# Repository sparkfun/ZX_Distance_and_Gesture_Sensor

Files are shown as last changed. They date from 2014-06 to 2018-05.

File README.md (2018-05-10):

**NOTE:** *This product has been retired from our catalog. If you are looking for more up-to-date info, please check out some of these resources to see how other users are still hacking and improving on this product.*
* *[SparkFun Forum](https://forum.sparkfun.com/)*
* *[Comments Here on GitHub](https://github.com/sparkfun/ZX_Distance_and_Gesture_Sensor/issues)*
* *[IRC Channel](https://www.sparkfun.com/news/263)*

There is another version available with the surface mount ICs [ ZX Distance and Gesture Sensor SMD - [SEN-13162](https://www.sparkfun.com/products/13162) ] so the associated Arduino Library will be kept open => [SparkFun_ZX_distance_and_Gesture_Sensor_Arduino_Library](https://github.com/sparkfun/SparkFun_ZX_Distance_and_Gesture_Sensor_Arduino_Library). 

SparkFun ZX Distance and Gesture Sensor
========================================

SparkFun ZX Distance and Gesture Sensor

[*SparkFun ZX Distance and Gesture Sensor (SEN-12780)*](https://www.sparkfun.com/products/12780)

Infrared sensor capable of determining an object's distance from the sensor and its relative position between the IR LEDs. The sensor is capable of determining a 2-dimensional location of an object as well as determining several basic gestures.

Repository Contents
-------------------

* **/Hardware** - Eagle design files (.brd, .sch)
* **/Libraries** - Libraries for use with the ZX Distance and Gesture Sensor
* **/Production** - Production panel files (.brd)

Documentation
--------------

* **[Library](https://github.com/sparkfun/SparkFun_ZX_Distance_and_Gesture_Sensor_Arduino_Library)** - Arduino library for the ZX Distance and Gesture Sensor.
* **[Hookup Guide](https://learn.sparkfun.com/tutorials/zx-distance-and-gesture-sensor-hookup-guide)** - Basic hookup guide for the ZX Distance and Gesture Sensor.
* **[SparkFun Fritzing repo](https://github.com/sparkfun/Fritzing_Parts)** - Fritzing diagrams for SparkFun products.

Product Versions
----------------

* [SEN-12780](https://www.sparkfun.com/products/12780)- ZX Distance and Gesture Sensor

Version History
---------------

* [H_1.0_L_1.0.2](https://github.com/sparkfun/ZX_Distance_and_Gesture_Sensor/tree/H_1.0_L_1.0.2) - Fixed Arduino library name
* [H_1.0_L_1.0.1](https://github.com/sparkfun/ZX_Distance_and_Gesture_Sensor/tree/H_1.0_L_1.0.1) - Fixed typo in Arduino library properties file
* [H_1.0_L_1.0.0](https://github.com/sparkfun/ZX_Distance_and_Gesture_Sensor/tree/H_1.0_L_1.0.0) - Initial release

License Information
-------------------

This product is _**open source**_! 

Please review the LICENSE.md file for license information. 

If you have any questions or concerns on licensing, please contact techsupport@sparkfun.com.

Distributed as-is; no warranty is given.

- Your friends at SparkFun.

_This is a collaboration with [XYZ Interactive](http://www.gesturesense.com/xyz)_

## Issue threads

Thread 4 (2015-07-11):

ZX_RRNG address correct?

akohlsmith, 2015-07-11:
I'm the author of the ZX software (the software in the sensor itself). Are you sure that you have the ZX_RRNG address correct? REGVER 0x01 MODEL 0x01 should not report anything at register 0x0e (i.e. reading register 0x0e will always return zero).

If you could verify this behaviour this on your production sensors I'll fork the code and send a pull request.

ShawnHymel, 2015-08-13:
Hi Andrew, sorry it's taken me so long to get to this bug. I spit out the contents of LRNG and RRNG from our production ZX Sensor, and they both read "0." According to the [I2C Register Map](https://cdn.sparkfun.com/datasheets/Sensors/Proximity/XYZ%20I2C%20Registers%20v1.zip) that XYZ sent me, LRNG and RRNG are implemented. I just don't see them doing any thing right now. I don't mind leaving the definitions in, because they aren't used in the code.

bboyho, 2018-05-10:
Unfortunately, the ZX distance and gesture sensor [SKU-12780](https://www.sparkfun.com/products/retired/12780) has been retired. This looks like the issue has been addressed and will be left as is.  I will be closing this issue and archiving the GitHub repository.

There is another version available with the surface mount ICs [ ZX Distance and Gesture Sensor SMD [SEN-13162](https://www.sparkfun.com/products/13162) ] so the associated Arduino Library will be kept open [SparkFun_ZX_distance_and_Gesture_Sensor_Arduino_Library](https://github.com/sparkfun/SparkFun_ZX_Distance_and_Gesture_Sensor_Arduino_Library).

Closed 2018-05-10.

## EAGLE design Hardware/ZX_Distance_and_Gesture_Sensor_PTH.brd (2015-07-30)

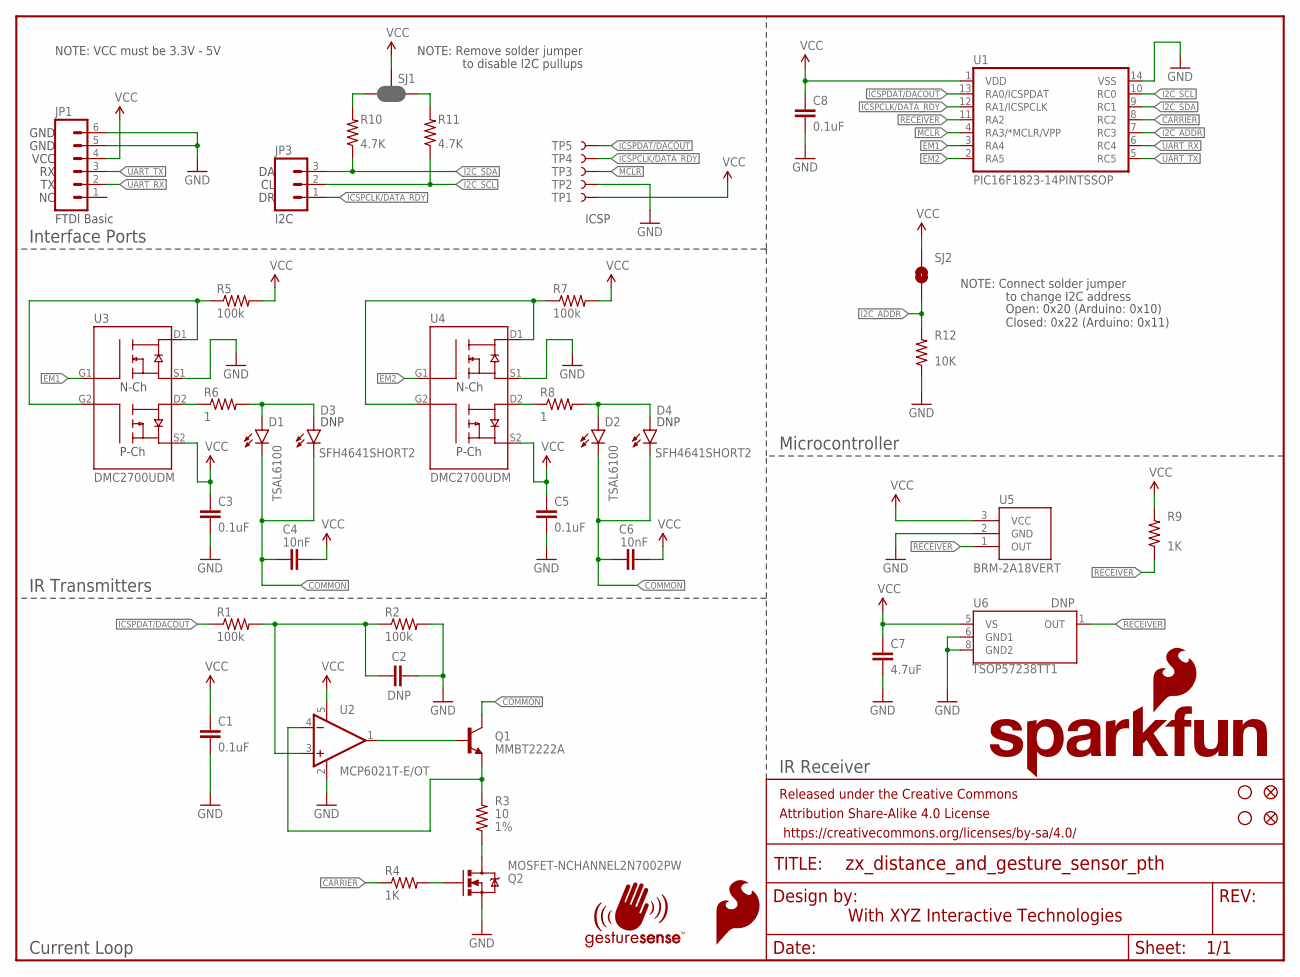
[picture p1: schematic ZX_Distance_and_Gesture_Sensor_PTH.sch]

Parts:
C1, C3, C5, C8: 0.1uF; 0603-CAP
C2: DNP; 0603-CAP
C4, C6: 10nF; 0603-CAP
C7: 4.7uF; 0603-CAP
D1, D2: LED-IR-THRUTSAL6100; LED5MM
D3, D4: SFH4641SHORT2; SFH4641-SHORT2
FID1, FID2: FIDUCIAL1X2; FIDUCIAL-1X2
FRAME1: FRAME-LETTER; CREATIVE_COMMONS
JP1: M06NO_SILK_FEMALE_PTH; 1X06_NO_SILK
JP3: M031X03_NO_SILK; 1X03_NO_SILK
LOGO1: SFE_LOGO_FLAME.1_INCH; SFE_LOGO_FLAME_.1
Q1: MMBT2222A; SOT23-3
Q2: MOSFET-NCHANNEL2N7002PW; SOT323
R1, R2, R5, R7: 100k; 0603-RES
R3: 10; 0603-RES
R4, R9: 1K; 0603-RES
R6, R8: 1; 0603-RES
R10, R11: 4.7K; 0603-RES
R12: 10K; 0603-RES
SJ1: JUMPER-PAD-3-NC_BY_PASTE; PAD-JUMPER-3-NC_BY_PASTE_YES_SILK_FULL_BOX
SJ2: JUMPER-PAD-2-NOYES_SILK; PAD-JUMPER-2-NO_YES_SILK
STANDOFF1, STANDOFF2: STAND-OFF
TP1, TP2, TP3, TP4, TP5: TEST-POINT3X4; PAD.03X.04
U1: PIC16F1823-14PINTSSOP; TSSOP14
U2: MCP6021T-E/OT; SOT23-5
U3, U4: DMC2700UDM; SOT26
U5: BRM-2A18VERT; BRM-2508_VERT
U6: TSOP57238TT1; TSOP572
U$5: SFE_LOGO_NAME_FLAME.1_INCH; SFE_LOGO_NAME_FLAME_.1
U$6: GESTURESENSE_LOGOSTEXT; GESTURESENSE_TEXT

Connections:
CARRIER: R4.1, U1.8 (RC2)
COMMON: C4.1, C6.1, D1.K (C), D2.K (C), D3.C, D4.C, Q1.3 (C)
EM1: U1.3 (RA4), U3.G1
EM2: U1.2 (RA5), U4.G1
GND: C1.2, C2.2, C3.2, C5.2, C7.2, C8.2, JP1.5, JP1.6, Q2.2 (S), R2.2, R12.1, TP2.P$1, U1.14 (VSS), U2.2 (V-), U3.S1, U4.S1, U5.2 (GND), U6.6 (GND1), U6.8 (GND2)
I2C_ADDR: R12.2, SJ2.1, U1.7 (RC3)
I2C_SCL: JP3.2, R11.1, U1.10 (RC0)
I2C_SDA: JP3.3, R10.1, U1.9 (RC1)
ICSPCLK/DATA_RDY: JP3.1, TP4.P$1, U1.12 (RA1/ICSPCLK)
ICSPDAT/DACOUT: R1.1, TP5.P$1, U1.13 (RA0/ICSPDAT)
MCLR: TP3.P$1, U1.4 (RA3/*MCLR/VPP)
unnamed: C2.1, R1.2, R2.1, U2.3 (+IN)
unnamed: Q1.2 (E), R3.2, U2.4 (-IN)
unnamed: Q1.1 (B), U2.1 (OUT)
unnamed: Q2.3 (D), R3.1
unnamed: Q2.1 (G), R4.2
unnamed: R6.1, U3.D2
unnamed: D1.A, D3.A, R6.2
unnamed: R5.1, U3.D1, U3.G2
unnamed: R7.1, U4.D1, U4.G2
unnamed: R10.2, SJ1.3
unnamed: R8.1, U4.D2
unnamed: D2.A, D4.A, R8.2
unnamed: R11.2, SJ1.1
RECEIVER: R9.1, U1.11 (RA2), U5.1 (OUT), U6.1 (OUT)
UART_RX: JP1.2, U1.6 (RC4)
UART_TX: JP1.3, U1.5 (RC5)
VCC: C1.1, C3.1, C4.2, C5.1, C6.2, C7.1, C8.1, JP1.4, R5.2, R7.2, R9.2, SJ1.2, SJ2.2, TP1.P$1, U1.1 (VDD), U2.5 (V+), U3.S2, U4.S2, U5.3 (VCC), U6.5 (VS)

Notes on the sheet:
With XYZ Interactive Technologies
FTDI Basic
I2C
ICSP
NOTE: Remove solder jumper
to disable I2C pullups
NOTE: Connect solder jumper
to change I2C address
Open: 0x20 (Arduino: 0x10) Closed: 0x22 (Arduino: 0x11)
Interface Ports
IR Transmitters
Current Loop
Microcontroller
IR Receiver
VCC
GND
DNP
NOTE: VCC must be 3.3V - 5V

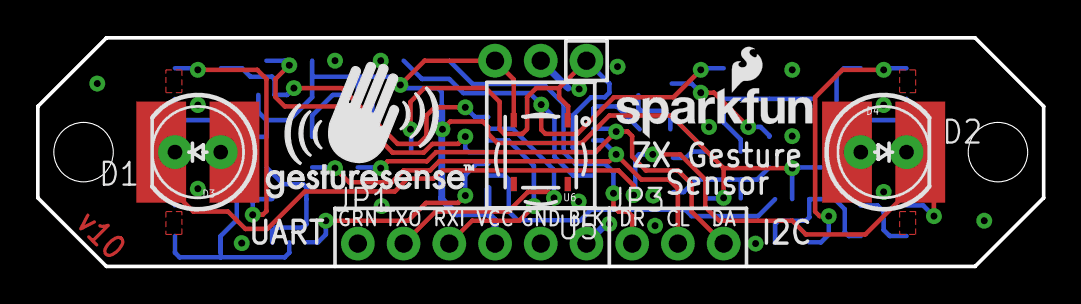
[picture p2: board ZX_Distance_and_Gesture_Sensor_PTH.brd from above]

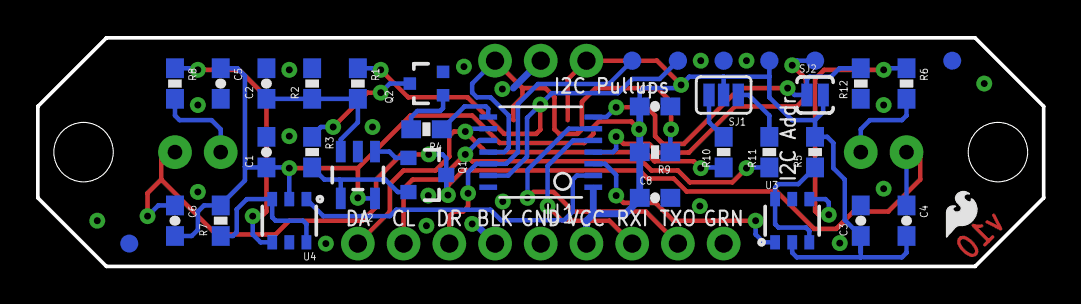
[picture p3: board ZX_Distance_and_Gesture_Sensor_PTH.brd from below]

Board: 2 copper layers, 55.9 x 12.7 mm, 49 parts (36 on the bottom side), 28 nets.

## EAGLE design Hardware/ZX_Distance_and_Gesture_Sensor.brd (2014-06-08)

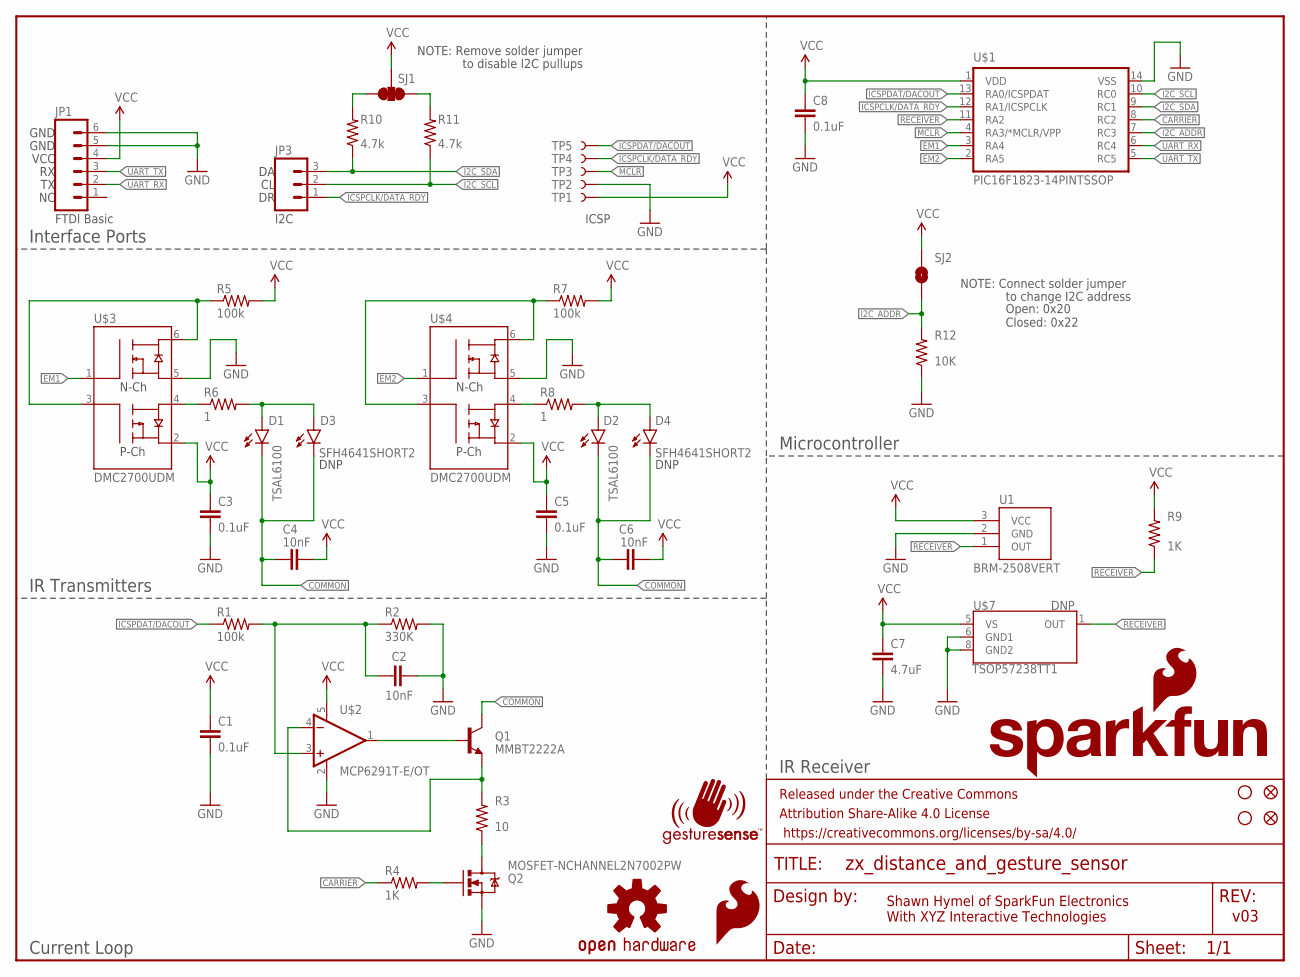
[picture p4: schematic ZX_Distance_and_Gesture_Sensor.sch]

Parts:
C1, C3, C5, C8: 0.1uF; 0603-CAP
C2, C4, C6: 10nF; 0603-CAP
C7: 4.7uF; 0603-CAP
D1, D2: LED-IR-THRUTSAL6100; LED5MM
D3, D4: SFH4641SHORT2; SFH4641-SHORT2
FID1, FID2: FIDUCIAL1X2; FIDUCIAL-1X2
FRAME1: FRAME-LETTER; CREATIVE_COMMONS
JP1: M06NO_SILK; 1X06_NO_SILK
JP3: M031X03_NO_SILK; 1X03_NO_SILK
LOGO1: SFE_LOGO_FLAME.1_INCH; SFE_LOGO_FLAME_.1
LOGO2: OSHW-LOGOS; OSHW-LOGO-S
Q1: MMBT2222A; SOT23-3
Q2: MOSFET-NCHANNEL2N7002PW; SOT323
R1, R5, R7: 100k; 0603-RES
R2: 330K; 0603-RES
R3: 10; 0603-RES
R4, R9: 1K; 0603-RES
R6, R8: 1; 0603-RES
R10, R11: 4.7k; 0603
R12: 10K; 0603-RES
SJ1: SOLDERJUMPER_2WAYPASTE1&2&3; SJ_3_PASTE1&2&3
SJ2: SOLDERJUMPERNO; SJ_2S-NO
STANDOFF1, STANDOFF2: STAND-OFF
TP1, TP2, TP3, TP4, TP5: TEST-POINT3X4; PAD.03X.04
U1: BRM-2508VERT; BRM-2508_VERT
U$1: PIC16F1823-14PINTSSOP; TSSOP14
U$2: MCP6291T-E/OT; SOT23-5
U$3, U$4: DMC2700UDM; SOT26
U$5: SFE_LOGO_NAME_FLAME.1_INCH; SFE_LOGO_NAME_FLAME_.1
U$6: GESTURESENSE_LOGOSTEXT; GESTURESENSE_TEXT
U$7: TSOP57238TT1; TSOP572

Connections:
CARRIER: R4.1, U$1.8 (RC2)
COMMON: C4.1, C6.1, D1.K (C), D2.K (C), D3.C, D4.C, Q1.3 (C)
EM1: U$1.3 (RA4), U$3.1 (G1)
EM2: U$1.2 (RA5), U$4.1 (G1)
GND: C1.2, C2.2, C3.2, C5.2, C7.2, C8.2, JP1.5, JP1.6, Q2.2 (S), R2.2, R12.1, TP2.P$1, U1.2 (GND), U$1.14 (VSS), U$2.2 (V-), U$3.5 (S1), U$4.5 (S1), U$7.6 (GND1), U$7.8 (GND2)
I2C_ADDR: R12.2, SJ2.1, U$1.7 (RC3)
I2C_SCL: JP3.2, R11.1, U$1.10 (RC0)
I2C_SDA: JP3.3, R10.1, U$1.9 (RC1)
ICSPCLK/DATA_RDY: JP3.1, TP4.P$1, U$1.12 (RA1/ICSPCLK)
ICSPDAT/DACOUT: R1.1, TP5.P$1, U$1.13 (RA0/ICSPDAT)
MCLR: TP3.P$1, U$1.4 (RA3/*MCLR/VPP)
unnamed: C2.1, R1.2, R2.1, U$2.3 (+IN)
unnamed: Q1.2 (E), R3.2, U$2.4 (-IN)
unnamed: Q1.1 (B), U$2.1 (OUT)
unnamed: Q2.3 (D), R3.1
unnamed: Q2.1 (G), R4.2
unnamed: R6.1, U$3.4 (D2)
unnamed: D1.A, D3.A, R6.2
unnamed: R5.1, U$3.3 (G2), U$3.6 (D1)
unnamed: R7.1, U$4.3 (G2), U$4.6 (D1)
unnamed: R10.2, SJ1.3
unnamed: R8.1, U$4.4 (D2)
unnamed: D2.A, D4.A, R8.2
unnamed: R11.2, SJ1.1
RECEIVER: R9.1, U1.1 (OUT), U$1.11 (RA2), U$7.1 (OUT)
UART_RX: JP1.2, U$1.6 (RC4)
UART_TX: JP1.3, U$1.5 (RC5)
VCC: C1.1, C3.1, C4.2, C5.1, C6.2, C7.1, C8.1, JP1.4, R5.2, R7.2, R9.2, SJ1.2, SJ2.2, TP1.P$1, U1.3 (VCC), U$1.1 (VDD), U$2.5 (V+), U$3.2 (S2), U$4.2 (S2), U$7.5 (VS)

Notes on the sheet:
v03
Shawn Hymel of SparkFun Electronics With XYZ Interactive Technologies
FTDI Basic
I2C
ICSP
NOTE: Remove solder jumper
to disable I2C pullups
NOTE: Connect solder jumper
to change I2C address
Open: 0x20 Closed: 0x22
Interface Ports
IR Transmitters
Current Loop
Microcontroller
IR Receiver
VCC
GND
DNP

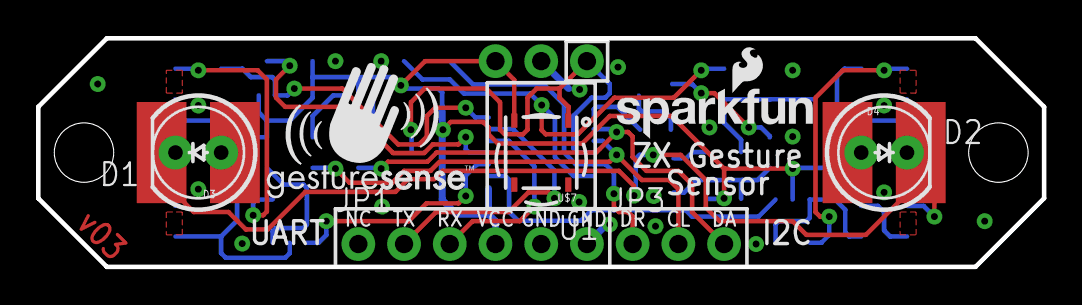
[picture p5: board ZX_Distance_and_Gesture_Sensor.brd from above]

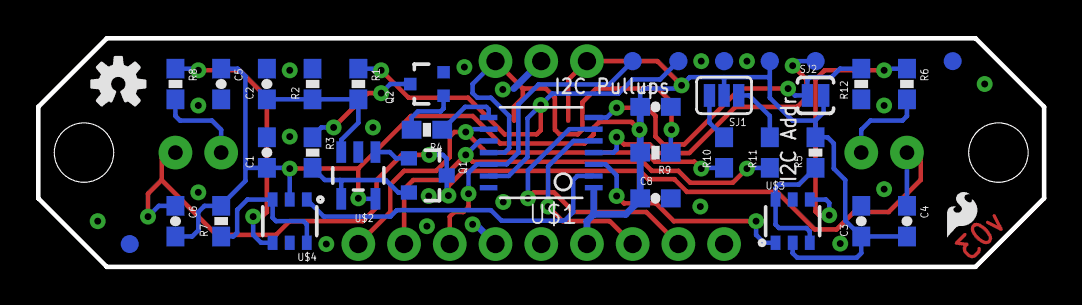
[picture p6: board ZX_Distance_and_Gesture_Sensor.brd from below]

Board: 2 copper layers, 55.9 x 12.7 mm, 50 parts (37 on the bottom side), 28 nets.

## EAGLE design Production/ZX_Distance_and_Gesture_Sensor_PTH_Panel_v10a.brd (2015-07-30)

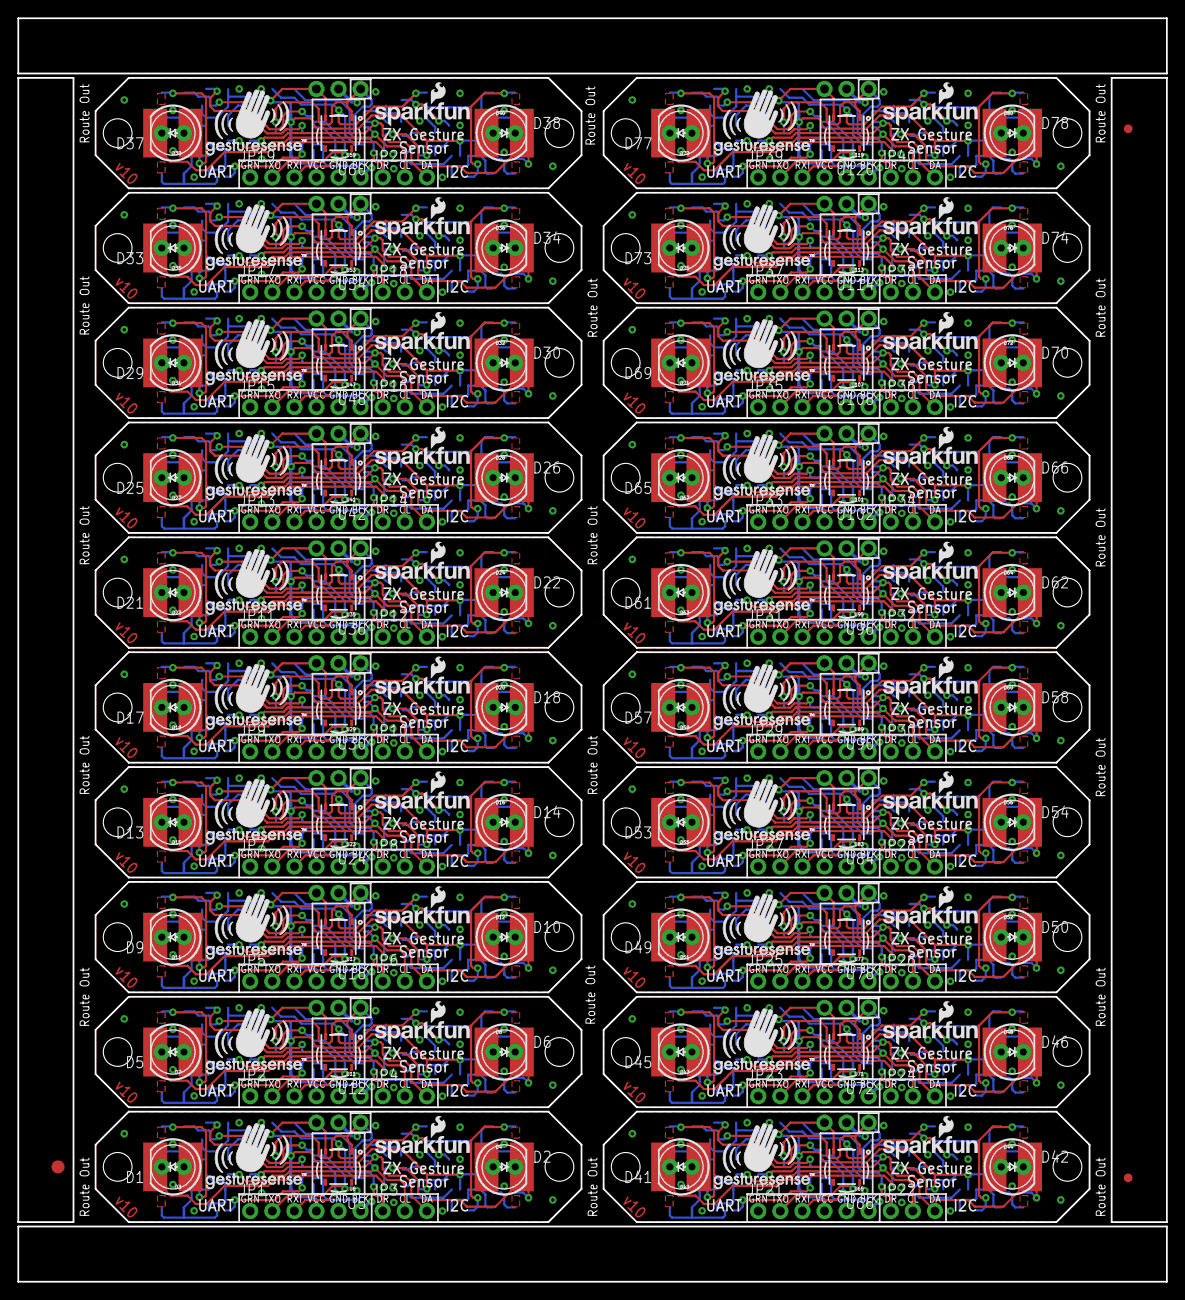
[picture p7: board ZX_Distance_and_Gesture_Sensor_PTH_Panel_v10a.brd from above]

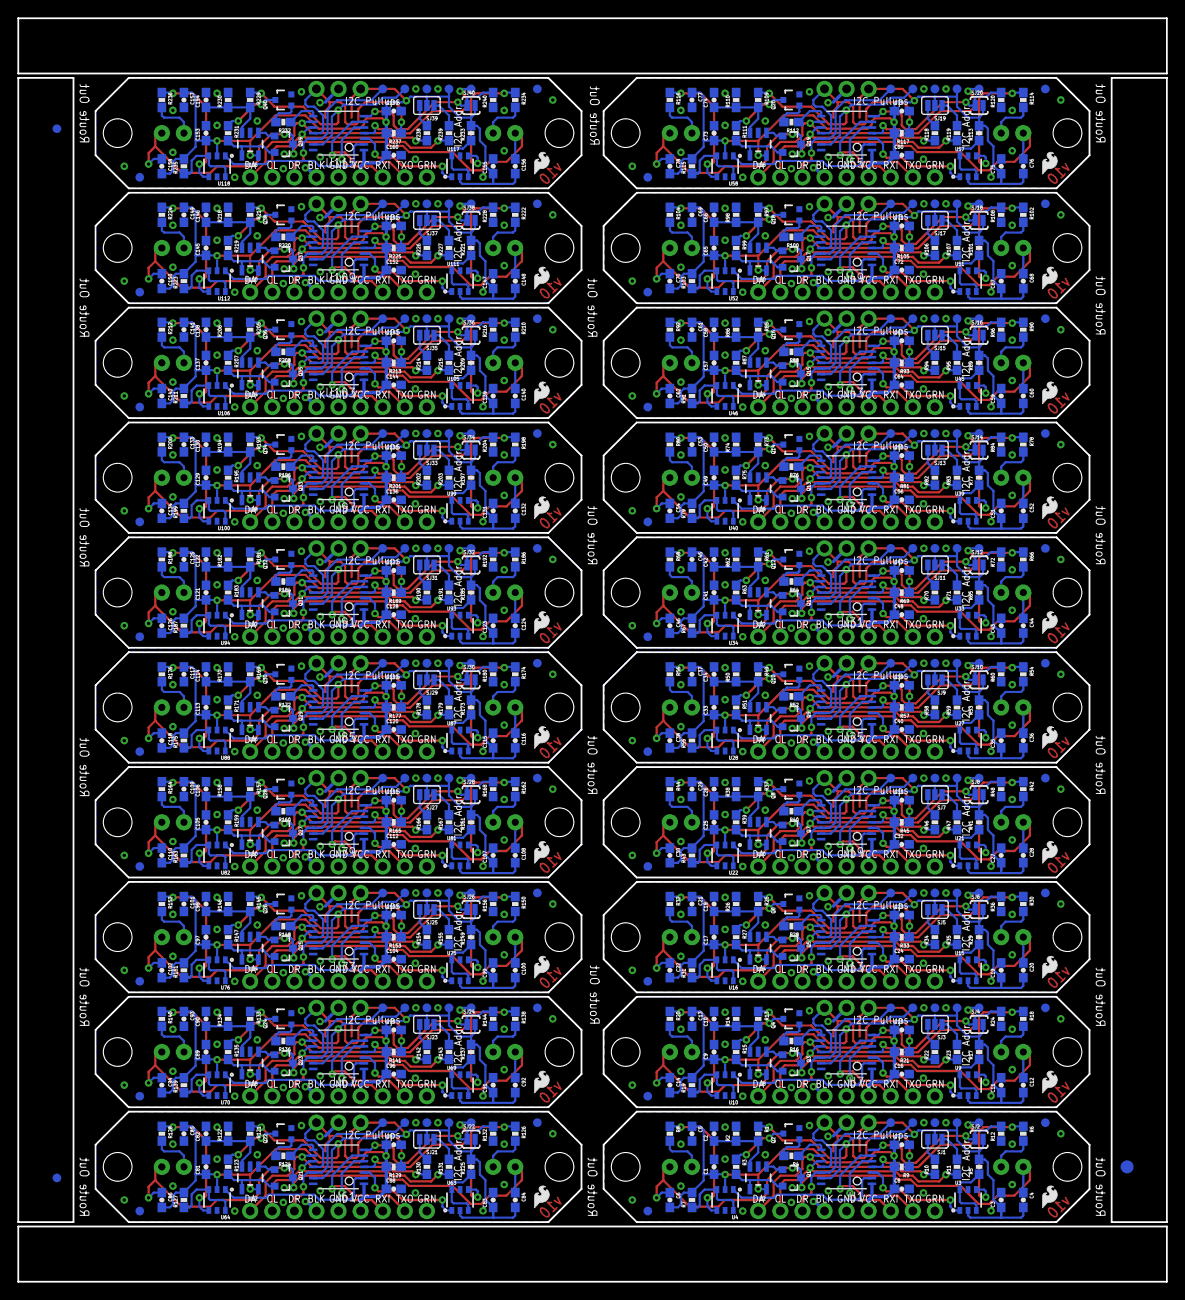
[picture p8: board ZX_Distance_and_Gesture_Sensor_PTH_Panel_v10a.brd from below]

Board: 2 copper layers, 132.1 x 145.3 mm, 966 parts (723 on the bottom side), 560 nets.

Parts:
C1, C3, C5, C8, C9, C11, C13, C16, C17, C19, C21, C24, C25, C27, C29, C32, C33, C35, C37, C40, C41, C43, C45, C48, C49, C51, C53, C56, C57, C59, C61, C64, C65, C67, C69, C72, C73, C75, C77, C80, C81, C83, C85, C88, C89, C91, C93, C96, C97, C99, C101, C104, C105, C107, C109, C112, C113, C115, C117, C120, C121, C123, C125, C128, C129, C131, C133, C136, C137, C139, C141, C144, C145, C147, C149, C152, C153, C155, C157, C160: 0.1uF; 0603-CAP
C2, C10, C18, C26, C34, C42, C50, C58, C66, C74, C82, C90, C98, C106, C114, C122, C130, C138, C146, C154: DNP; 0603-CAP
C4, C6, C12, C14, C20, C22, C28, C30, C36, C38, C44, C46, C52, C54, C60, C62, C68, C70, C76, C78, C84, C86, C92, C94, C100, C102, C108, C110, C116, C118, C124, C126, C132, C134, C140, C142, C148, C150, C156, C158: 10nF; 0603-CAP
C7, C15, C23, C31, C39, C47, C55, C63, C71, C79, C87, C95, C103, C111, C119, C127, C135, C143, C151, C159: 4.7uF; 0603-CAP
D1, D2, D5, D6, D9, D10, D13, D14, D17, D18, D21, D22, D25, D26, D29, D30, D33, D34, D37, D38, D41, D42, D45, D46, D49, D50, D53, D54, D57, D58, D61, D62, D65, D66, D69, D70, D73, D74, D77, D78: LED-IR-THRUTSAL6100; LED5MM
D3, D4, D7, D8, D11, D12, D15, D16, D19, D20, D23, D24, D27, D28, D31, D32, D35, D36, D39, D40, D43, D44, D47, D48, D51, D52, D55, D56, D59, D60, D63, D64, D67, D68, D71, D72, D75, D76, D79, D80: SFH4641SHORT2; SFH4641-SHORT2
E$1, E$3: FIDUCIAL-1.5X3
E$2, E$4, E$5, E$6: FIDUCIAL-1X2
FID1, FID2, FID3, FID4, FID5, FID6, FID7, FID8, FID9, FID10, FID11, FID12, FID13, FID14, FID15, FID16, FID17, FID18, FID19, FID20, FID21, FID22, FID23, FID24, FID25, FID26, FID27, FID28, FID29, FID30, FID31, FID32, FID33, FID34, FID35, FID36, FID37, FID38, FID39, FID40: FIDUCIAL1X2; FIDUCIAL-1X2
JP1, JP2, JP5, JP7, JP9, JP11, JP13, JP15, JP17, JP19, JP21, JP23, JP25, JP27, JP29, JP31, JP33, JP35, JP37, JP39: 1X06_NO_SILK
JP3, JP4, JP6, JP8, JP10, JP12, JP14, JP16, JP18, JP20, JP22, JP24, JP26, JP28, JP30, JP32, JP34, JP36, JP38, JP40: 1X03_NO_SILK
LOGO1, LOGO2, LOGO3, LOGO4, LOGO5, LOGO6, LOGO7, LOGO8, LOGO9, LOGO10, LOGO11, LOGO12, LOGO13, LOGO14, LOGO15, LOGO16, LOGO17, LOGO18, LOGO19, LOGO20: SFE_LOGO_FLAME.1_INCH; SFE_LOGO_FLAME_.1
Q1, Q3, Q5, Q7, Q9, Q11, Q13, Q15, Q17, Q19, Q21, Q23, Q25, Q27, Q29, Q31, Q33, Q35, Q37, Q39: MMBT2222A; SOT23-3
Q2, Q4, Q6, Q8, Q10, Q12, Q14, Q16, Q18, Q20, Q22, Q24, Q26, Q28, Q30, Q32, Q34, Q36, Q38, Q40: MOSFET-NCHANNEL2N7002PW; SOT323
R1, R2, R5, R7, R13, R14, R17, R19, R25, R26, R29, R31, R37, R38, R41, R43, R49, R50, R53, R55, R61, R62, R65, R67, R73, R74, R77, R79, R85, R86, R89, R91, R97, R98, R101, R103, R109, R110, R113, R115, R121, R122, R125, R127, R133, R134, R137, R139, R145, R146, R149, R151, R157, R158, R161, R163, R169, R170, R173, R175, R181, R182, R185, R187, R193, R194, R197, R199, R205, R206, R209, R211, R217, R218, R221, R223, R229, R230, R233, R235: 100k; 0603-RES
R3, R15, R27, R39, R51, R63, R75, R87, R99, R111, R123, R135, R147, R159, R171, R183, R195, R207, R219, R231: 10; 0603-RES
R4, R9, R16, R21, R28, R33, R40, R45, R52, R57, R64, R69, R76, R81, R88, R93, R100, R105, R112, R117, R124, R129, R136, R141, R148, R153, R160, R165, R172, R177, R184, R189, R196, R201, R208, R213, R220, R225, R232, R237: 1K; 0603-RES
R6, R8, R18, R20, R30, R32, R42, R44, R54, R56, R66, R68, R78, R80, R90, R92, R102, R104, R114, R116, R126, R128, R138, R140, R150, R152, R162, R164, R174, R176, R186, R188, R198, R200, R210, R212, R222, R224, R234, R236: 1; 0603-RES
R10, R11, R22, R23, R34, R35, R46, R47, R58, R59, R70, R71, R82, R83, R94, R95, R106, R107, R118, R119, R130, R131, R142, R143, R154, R155, R166, R167, R178, R179, R190, R191, R202, R203, R214, R215, R226, R227, R238, R239: 4.7K; 0603-RES
R12, R24, R36, R48, R60, R72, R84, R96, R108, R120, R132, R144, R156, R168, R180, R192, R204, R216, R228, R240: 10K; 0603-RES
SJ1, SJ3, SJ5, SJ7, SJ9, SJ11, SJ13, SJ15, SJ17, SJ19, SJ21, SJ23, SJ25, SJ27, SJ29, SJ31, SJ33, SJ35, SJ37, SJ39: JUMPER-PAD-3-NC_BY_PASTE; PAD-JUMPER-3-NC_BY_PASTE_YES_SILK_FULL_BOX
SJ2, SJ4, SJ6, SJ8, SJ10, SJ12, SJ14, SJ16, SJ18, SJ20, SJ22, SJ24, SJ26, SJ28, SJ30, SJ32, SJ34, SJ36, SJ38, SJ40: JUMPER-PAD-2-NOYES_SILK; PAD-JUMPER-2-NO_YES_SILK
STANDOFF1, STANDOFF2, STANDOFF3, STANDOFF4, STANDOFF5, STANDOFF6, STANDOFF7, STANDOFF8, STANDOFF9, STANDOFF10, STANDOFF11, STANDOFF12, STANDOFF13, STANDOFF14, STANDOFF15, STANDOFF16, STANDOFF17, STANDOFF18, STANDOFF19, STANDOFF20, STANDOFF21, STANDOFF22, STANDOFF23, STANDOFF24, STANDOFF25, STANDOFF26, STANDOFF27, STANDOFF28, STANDOFF29, STANDOFF30, STANDOFF31, STANDOFF32, STANDOFF33, STANDOFF34, STANDOFF35, STANDOFF36, STANDOFF37, STANDOFF38, STANDOFF39, STANDOFF40: STAND-OFF
TP1, TP2, TP3, TP4, TP5, TP6, TP7, TP8, TP9, TP10, TP11, TP12, TP13, TP14, TP15, TP16, TP17, TP18, TP19, TP20, TP21, TP22, TP23, TP24, TP25, TP26, TP27, TP28, TP29, TP30, TP31, TP32, TP33, TP34, TP35, TP36, TP37, TP38, TP39, TP40, TP41, TP42, TP43, TP44, TP45, TP46, TP47, TP48, TP49, TP50, TP51, TP52, TP53, TP54, TP55, TP56, TP57, TP58, TP59, TP60, TP61, TP62, TP63, TP64, TP65, TP66, TP67, TP68, TP69, TP70, TP71, TP72, TP73, TP74, TP75, TP76, TP77, TP78, TP79, TP80, TP81, TP82, TP83, TP84, TP85, TP86, TP87, TP88, TP89, TP90, TP91, TP92, TP93, TP94, TP95, TP96, TP97, TP98, TP99, TP100: TEST-POINT3X4; PAD.03X.04
U1, U7, U13, U19, U25, U31, U37, U43, U49, U55, U61, U67, U73, U79, U85, U91, U97, U103, U109, U115: PIC16F1823-14PINTSSOP; TSSOP14
U2, U8, U14, U20, U26, U32, U38, U44, U50, U56, U62, U68, U74, U80, U86, U92, U98, U104, U110, U116: MCP6021T-E/OT; SOT23-5
U3, U4, U9, U10, U15, U16, U21, U22, U27, U28, U33, U34, U39, U40, U45, U46, U51, U52, U57, U58, U63, U64, U69, U70, U75, U76, U81, U82, U87, U88, U93, U94, U99, U100, U105, U106, U111, U112, U117, U118: DMC2700UDM; SOT26
U5, U12, U18, U24, U30, U36, U42, U48, U54, U60, U66, U72, U78, U84, U90, U96, U102, U108, U114, U120: BRM-2A18VERT; BRM-2508_VERT
U6, U11, U17, U23, U29, U35, U41, U47, U53, U59, U65, U71, U77, U83, U89, U95, U101, U107, U113, U119: TSOP57238TT1; TSOP572
U$1, U$3, U$5, U$7, U$9, U$11, U$13, U$15, U$17, U$19, U$21, U$23, U$25, U$27, U$29, U$31, U$33, U$35, U$37, U$39: SFE_LOGO_NAME_FLAME.1_INCH; SFE_LOGO_NAME_FLAME_.1
U$2, U$4, U$6, U$8, U$10, U$12, U$14, U$16, U$18, U$20, U$22, U$24, U$26, U$28, U$30, U$32, U$34, U$36, U$38, U$40: GESTURESENSE_LOGOSTEXT; GESTURESENSE_TEXT

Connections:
CARRIER: R4.1, U1.8
CARRIER1: R16.1, U7.8
CARRIER2: R28.1, U13.8
CARRIER3: R40.1, U19.8
CARRIER4: R52.1, U25.8
CARRIER5: R64.1, U31.8
CARRIER6: R76.1, U37.8
CARRIER7: R88.1, U43.8
CARRIER8: R100.1, U49.8
CARRIER9: R112.1, U55.8
CARRIER10: R124.1, U61.8
CARRIER11: R136.1, U67.8
CARRIER12: R148.1, U73.8
CARRIER13: R160.1, U79.8
CARRIER14: R172.1, U85.8
CARRIER15: R184.1, U91.8
CARRIER16: R196.1, U97.8
CARRIER17: R208.1, U103.8
CARRIER18: R220.1, U109.8
CARRIER19: R232.1, U115.8
COMMON: C4.1, C6.1, D1.K, D2.K, D3.C, D4.C, Q1.3
COMMON1: C12.1, C14.1, D5.K, D6.K, D7.C, D8.C, Q3.3
COMMON2: C20.1, C22.1, D9.K, D10.K, D11.C, D12.C, Q5.3
COMMON3: C28.1, C30.1, D13.K, D14.K, D15.C, D16.C, Q7.3
COMMON4: C36.1, C38.1, D17.K, D18.K, D19.C, D20.C, Q9.3
COMMON5: C44.1, C46.1, D21.K, D22.K, D23.C, D24.C, Q11.3
COMMON6: C52.1, C54.1, D25.K, D26.K, D27.C, D28.C, Q13.3
COMMON7: C60.1, C62.1, D29.K, D30.K, D31.C, D32.C, Q15.3
COMMON8: C68.1, C70.1, D33.K, D34.K, D35.C, D36.C, Q17.3
COMMON9: C76.1, C78.1, D37.K, D38.K, D39.C, D40.C, Q19.3
COMMON10: C84.1, C86.1, D41.K, D42.K, D43.C, D44.C, Q21.3
COMMON11: C92.1, C94.1, D45.K, D46.K, D47.C, D48.C, Q23.3
COMMON12: C100.1, C102.1, D49.K, D50.K, D51.C, D52.C, Q25.3
COMMON13: C108.1, C110.1, D53.K, D54.K, D55.C, D56.C, Q27.3
COMMON14: C116.1, C118.1, D57.K, D58.K, D59.C, D60.C, Q29.3
COMMON15: C124.1, C126.1, D61.K, D62.K, D63.C, D64.C, Q31.3
COMMON16: C132.1, C134.1, D65.K, D66.K, D67.C, D68.C, Q33.3
COMMON17: C140.1, C142.1, D69.K, D70.K, D71.C, D72.C, Q35.3
COMMON18: C148.1, C150.1, D73.K, D74.K, D75.C, D76.C, Q37.3
COMMON19: C156.1, C158.1, D77.K, D78.K, D79.C, D80.C, Q39.3
EM1: U1.3, U3.G1
EM2: U1.2, U4.G1
EM3: U7.3, U9.G1
EM4: U7.2, U10.G1
EM5: U13.3, U15.G1
EM6: U13.2, U16.G1
EM7: U19.3, U21.G1
EM8: U19.2, U22.G1
EM9: U25.3, U27.G1
EM10: U25.2, U28.G1
EM11: U31.3, U33.G1
EM12: U31.2, U34.G1
EM13: U37.3, U39.G1
EM14: U37.2, U40.G1
EM15: U43.3, U45.G1
EM16: U43.2, U46.G1
EM17: U49.3, U51.G1
EM18: U49.2, U52.G1
EM19: U55.3, U57.G1
EM20: U55.2, U58.G1
EM21: U61.3, U63.G1
EM22: U61.2, U64.G1
EM23: U67.3, U69.G1
EM24: U67.2, U70.G1
EM25: U73.3, U75.G1
EM26: U73.2, U76.G1
EM27: U79.3, U81.G1
EM28: U79.2, U82.G1
EM29: U85.3, U87.G1
EM30: U85.2, U88.G1
EM31: U91.3, U93.G1
EM32: U91.2, U94.G1
EM33: U97.3, U99.G1
EM34: U97.2, U100.G1
EM35: U103.3, U105.G1
EM36: U103.2, U106.G1
EM37: U109.3, U111.G1
EM38: U109.2, U112.G1
EM39: U115.3, U117.G1
EM40: U115.2, U118.G1
GND: C1.2, C2.2, C3.2, C5.2, C7.2, C8.2, JP1.5, JP1.6, Q2.2, R2.2, R12.1, TP2.P$1, U1.14, U2.2, U3.S1, U4.S1, U5.2, U6.6, U6.8
GND1: C9.2, C10.2, C11.2, C13.2, C15.2, C16.2, JP2.5, JP2.6, Q4.2, R14.2, R24.1, TP7.P$1, U7.14, U8.2, U9.S1, U10.S1, U11.6, U11.8, U12.2
GND2: C17.2, C18.2, C19.2, C21.2, C23.2, C24.2, JP5.5, JP5.6, Q6.2, R26.2, R36.1, TP12.P$1, U13.14, U14.2, U15.S1, U16.S1, U17.6, U17.8, U18.2
GND3: C25.2, C26.2, C27.2, C29.2, C31.2, C32.2, JP7.5, JP7.6, Q8.2, R38.2, R48.1, TP17.P$1, U19.14, U20.2, U21.S1, U22.S1, U23.6, U23.8, U24.2
GND4: C33.2, C34.2, C35.2, C37.2, C39.2, C40.2, JP9.5, JP9.6, Q10.2, R50.2, R60.1, TP22.P$1, U25.14, U26.2, U27.S1, U28.S1, U29.6, U29.8, U30.2
GND5: C41.2, C42.2, C43.2, C45.2, C47.2, C48.2, JP11.5, JP11.6, Q12.2, R62.2, R72.1, TP27.P$1, U31.14, U32.2, U33.S1, U34.S1, U35.6, U35.8, U36.2
GND6: C49.2, C50.2, C51.2, C53.2, C55.2, C56.2, JP13.5, JP13.6, Q14.2, R74.2, R84.1, TP32.P$1, U37.14, U38.2, U39.S1, U40.S1, U41.6, U41.8, U42.2
GND7: C57.2, C58.2, C59.2, C61.2, C63.2, C64.2, JP15.5, JP15.6, Q16.2, R86.2, R96.1, TP37.P$1, U43.14, U44.2, U45.S1, U46.S1, U47.6, U47.8, U48.2
GND8: C65.2, C66.2, C67.2, C69.2, C71.2, C72.2, JP17.5, JP17.6, Q18.2, R98.2, R108.1, TP42.P$1, U49.14, U50.2, U51.S1, U52.S1, U53.6, U53.8, U54.2
GND9: C73.2, C74.2, C75.2, C77.2, C79.2, C80.2, JP19.5, JP19.6, Q20.2, R110.2, R120.1, TP47.P$1, U55.14, U56.2, U57.S1, U58.S1, U59.6, U59.8, U60.2
GND10: C81.2, C82.2, C83.2, C85.2, C87.2, C88.2, JP21.5, JP21.6, Q22.2, R122.2, R132.1, TP52.P$1, U61.14, U62.2, U63.S1, U64.S1, U65.6, U65.8, U66.2
GND11: C89.2, C90.2, C91.2, C93.2, C95.2, C96.2, JP23.5, JP23.6, Q24.2, R134.2, R144.1, TP57.P$1, U67.14, U68.2, U69.S1, U70.S1, U71.6, U71.8, U72.2
GND12: C97.2, C98.2, C99.2, C101.2, C103.2, C104.2, JP25.5, JP25.6, Q26.2, R146.2, R156.1, TP62.P$1, U73.14, U74.2, U75.S1, U76.S1, U77.6, U77.8, U78.2
GND13: C105.2, C106.2, C107.2, C109.2, C111.2, C112.2, JP27.5, JP27.6, Q28.2, R158.2, R168.1, TP67.P$1, U79.14, U80.2, U81.S1, U82.S1, U83.6, U83.8, U84.2
GND14: C113.2, C114.2, C115.2, C117.2, C119.2, C120.2, JP29.5, JP29.6, Q30.2, R170.2, R180.1, TP72.P$1, U85.14, U86.2, U87.S1, U88.S1, U89.6, U89.8, U90.2
GND15: C121.2, C122.2, C123.2, C125.2, C127.2, C128.2, JP31.5, JP31.6, Q32.2, R182.2, R192.1, TP77.P$1, U91.14, U92.2, U93.S1, U94.S1, U95.6, U95.8, U96.2
GND16: C129.2, C130.2, C131.2, C133.2, C135.2, C136.2, JP33.5, JP33.6, Q34.2, R194.2, R204.1, TP82.P$1, U97.14, U98.2, U99.S1, U100.S1, U101.6, U101.8, U102.2
GND17: C137.2, C138.2, C139.2, C141.2, C143.2, C144.2, JP35.5, JP35.6, Q36.2, R206.2, R216.1, TP87.P$1, U103.14, U104.2, U105.S1, U106.S1, U107.6, U107.8, U108.2
GND18: C145.2, C146.2, C147.2, C149.2, C151.2, C152.2, JP37.5, JP37.6, Q38.2, R218.2, R228.1, TP92.P$1, U109.14, U110.2, U111.S1, U112.S1, U113.6, U113.8, U114.2
GND19: C153.2, C154.2, C155.2, C157.2, C159.2, C160.2, JP39.5, JP39.6, Q40.2, R230.2, R240.1, TP97.P$1, U115.14, U116.2, U117.S1, U118.S1, U119.6, U119.8, U120.2
I2C_ADDR: R12.2, SJ2.1, U1.7
I2C_ADDR1: R24.2, SJ4.1, U7.7
I2C_ADDR2: R36.2, SJ6.1, U13.7
I2C_ADDR3: R48.2, SJ8.1, U19.7
I2C_ADDR4: R60.2, SJ10.1, U25.7
I2C_ADDR5: R72.2, SJ12.1, U31.7
I2C_ADDR6: R84.2, SJ14.1, U37.7
I2C_ADDR7: R96.2, SJ16.1, U43.7
I2C_ADDR8: R108.2, SJ18.1, U49.7
I2C_ADDR9: R120.2, SJ20.1, U55.7
I2C_ADDR10: R132.2, SJ22.1, U61.7
I2C_ADDR11: R144.2, SJ24.1, U67.7
I2C_ADDR12: R156.2, SJ26.1, U73.7
I2C_ADDR13: R168.2, SJ28.1, U79.7
I2C_ADDR14: R180.2, SJ30.1, U85.7
I2C_ADDR15: R192.2, SJ32.1, U91.7
I2C_ADDR16: R204.2, SJ34.1, U97.7
I2C_ADDR17: R216.2, SJ36.1, U103.7
I2C_ADDR18: R228.2, SJ38.1, U109.7
I2C_ADDR19: R240.2, SJ40.1, U115.7
I2C_SCL: JP3.2, R11.1, U1.10
I2C_SCL1: JP4.2, R23.1, U7.10
I2C_SCL2: JP6.2, R35.1, U13.10
I2C_SCL3: JP8.2, R47.1, U19.10
I2C_SCL4: JP10.2, R59.1, U25.10
I2C_SCL5: JP12.2, R71.1, U31.10
I2C_SCL6: JP14.2, R83.1, U37.10
I2C_SCL7: JP16.2, R95.1, U43.10
I2C_SCL8: JP18.2, R107.1, U49.10
I2C_SCL9: JP20.2, R119.1, U55.10
I2C_SCL10: JP22.2, R131.1, U61.10
I2C_SCL11: JP24.2, R143.1, U67.10
I2C_SCL12: JP26.2, R155.1, U73.10
I2C_SCL13: JP28.2, R167.1, U79.10
I2C_SCL14: JP30.2, R179.1, U85.10
I2C_SCL15: JP32.2, R191.1, U91.10
I2C_SCL16: JP34.2, R203.1, U97.10
I2C_SCL17: JP36.2, R215.1, U103.10
I2C_SCL18: JP38.2, R227.1, U109.10
I2C_SCL19: JP40.2, R239.1, U115.10
I2C_SDA: JP3.3, R10.1, U1.9
I2C_SDA1: JP4.3, R22.1, U7.9
I2C_SDA2: JP6.3, R34.1, U13.9
I2C_SDA3: JP8.3, R46.1, U19.9
I2C_SDA4: JP10.3, R58.1, U25.9
I2C_SDA5: JP12.3, R70.1, U31.9
I2C_SDA6: JP14.3, R82.1, U37.9
I2C_SDA7: JP16.3, R94.1, U43.9
I2C_SDA8: JP18.3, R106.1, U49.9
I2C_SDA9: JP20.3, R118.1, U55.9
I2C_SDA10: JP22.3, R130.1, U61.9
I2C_SDA11: JP24.3, R142.1, U67.9
I2C_SDA12: JP26.3, R154.1, U73.9
I2C_SDA13: JP28.3, R166.1, U79.9
I2C_SDA14: JP30.3, R178.1, U85.9
I2C_SDA15: JP32.3, R190.1, U91.9
I2C_SDA16: JP34.3, R202.1, U97.9
I2C_SDA17: JP36.3, R214.1, U103.9
I2C_SDA18: JP38.3, R226.1, U109.9
I2C_SDA19: JP40.3, R238.1, U115.9
ICSPCLK/DATA_RDY: JP3.1, TP4.P$1, U1.12
ICSPCLK/DATA_RDY1: JP4.1, TP9.P$1, U7.12
ICSPCLK/DATA_RDY2: JP6.1, TP14.P$1, U13.12
ICSPCLK/DATA_RDY3: JP8.1, TP19.P$1, U19.12
ICSPCLK/DATA_RDY4: JP10.1, TP24.P$1, U25.12
ICSPCLK/DATA_RDY5: JP12.1, TP29.P$1, U31.12
ICSPCLK/DATA_RDY6: JP14.1, TP34.P$1, U37.12
ICSPCLK/DATA_RDY7: JP16.1, TP39.P$1, U43.12
ICSPCLK/DATA_RDY8: JP18.1, TP44.P$1, U49.12
ICSPCLK/DATA_RDY9: JP20.1, TP49.P$1, U55.12
ICSPCLK/DATA_RDY10: JP22.1, TP54.P$1, U61.12
ICSPCLK/DATA_RDY11: JP24.1, TP59.P$1, U67.12
ICSPCLK/DATA_RDY12: JP26.1, TP64.P$1, U73.12
ICSPCLK/DATA_RDY13: JP28.1, TP69.P$1, U79.12
ICSPCLK/DATA_RDY14: JP30.1, TP74.P$1, U85.12
ICSPCLK/DATA_RDY15: JP32.1, TP79.P$1, U91.12
ICSPCLK/DATA_RDY16: JP34.1, TP84.P$1, U97.12
ICSPCLK/DATA_RDY17: JP36.1, TP89.P$1, U103.12
ICSPCLK/DATA_RDY18: JP38.1, TP94.P$1, U109.12
ICSPCLK/DATA_RDY19: JP40.1, TP99.P$1, U115.12
ICSPDAT/DACOUT: R1.1, TP5.P$1, U1.13
ICSPDAT/DACOUT1: R13.1, TP10.P$1, U7.13
ICSPDAT/DACOUT2: R25.1, TP15.P$1, U13.13
ICSPDAT/DACOUT3: R37.1, TP20.P$1, U19.13
ICSPDAT/DACOUT4: R49.1, TP25.P$1, U25.13
ICSPDAT/DACOUT5: R61.1, TP30.P$1, U31.13
ICSPDAT/DACOUT6: R73.1, TP35.P$1, U37.13
ICSPDAT/DACOUT7: R85.1, TP40.P$1, U43.13
ICSPDAT/DACOUT8: R97.1, TP45.P$1, U49.13
ICSPDAT/DACOUT9: R109.1, TP50.P$1, U55.13
ICSPDAT/DACOUT10: R121.1, TP55.P$1, U61.13
ICSPDAT/DACOUT11: R133.1, TP60.P$1, U67.13
ICSPDAT/DACOUT12: R145.1, TP65.P$1, U73.13
ICSPDAT/DACOUT13: R157.1, TP70.P$1, U79.13
ICSPDAT/DACOUT14: R169.1, TP75.P$1, U85.13
ICSPDAT/DACOUT15: R181.1, TP80.P$1, U91.13
ICSPDAT/DACOUT16: R193.1, TP85.P$1, U97.13
ICSPDAT/DACOUT17: R205.1, TP90.P$1, U103.13
ICSPDAT/DACOUT18: R217.1, TP95.P$1, U109.13
ICSPDAT/DACOUT19: R229.1, TP100.P$1, U115.13
MCLR: TP3.P$1, U1.4
MCLR1: TP8.P$1, U7.4
MCLR2: TP13.P$1, U13.4
MCLR3: TP18.P$1, U19.4
MCLR4: TP23.P$1, U25.4
MCLR5: TP28.P$1, U31.4
MCLR6: TP33.P$1, U37.4
MCLR7: TP38.P$1, U43.4
MCLR8: TP43.P$1, U49.4
MCLR9: TP48.P$1, U55.4
MCLR10: TP53.P$1, U61.4
MCLR11: TP58.P$1, U67.4
MCLR12: TP63.P$1, U73.4
MCLR13: TP68.P$1, U79.4
MCLR14: TP73.P$1, U85.4
MCLR15: TP78.P$1, U91.4
MCLR16: TP83.P$1, U97.4
MCLR17: TP88.P$1, U103.4
MCLR18: TP93.P$1, U109.4
MCLR19: TP98.P$1, U115.4
unnamed: C2.1, R1.2, R2.1, U2.3
unnamed: Q1.2, R3.2, U2.4
unnamed: Q1.1, U2.1
unnamed: Q2.3, R3.1
unnamed: Q2.1, R4.2
unnamed: R6.1, U3.D2
unnamed: D1.A, D3.A, R6.2
unnamed: R5.1, U3.D1, U3.G2
unnamed: R7.1, U4.D1, U4.G2
unnamed: R10.2, SJ1.3
unnamed: R8.1, U4.D2
unnamed: D2.A, D4.A, R8.2
unnamed: R11.2, SJ1.1
unnamed: C10.1, R13.2, R14.1, U8.3
unnamed: Q3.1, U8.1
unnamed: Q4.3, R15.1
unnamed: Q4.1, R16.2
unnamed: Q3.2, R15.2, U8.4
unnamed: R18.1, U9.D2
unnamed: D5.A, D7.A, R18.2
unnamed: R17.1, U9.D1, U9.G2
unnamed: R19.1, U10.D1, U10.G2
unnamed: R20.1, U10.D2
unnamed: D6.A, D8.A, R20.2
unnamed: R22.2, SJ3.3
unnamed: R23.2, SJ3.1
unnamed: C18.1, R25.2, R26.1, U14.3
unnamed: Q5.1, U14.1
unnamed: Q6.3, R27.1
unnamed: Q6.1, R28.2
unnamed: Q5.2, R27.2, U14.4
unnamed: R30.1, U15.D2
unnamed: D9.A, D11.A, R30.2
unnamed: R29.1, U15.D1, U15.G2
unnamed: R31.1, U16.D1, U16.G2
unnamed: R32.1, U16.D2
unnamed: D10.A, D12.A, R32.2
unnamed: R34.2, SJ5.3
unnamed: R35.2, SJ5.1
unnamed: C26.1, R37.2, R38.1, U20.3
unnamed: Q7.1, U20.1
unnamed: Q8.3, R39.1
unnamed: Q8.1, R40.2
unnamed: Q7.2, R39.2, U20.4
unnamed: R42.1, U21.D2
unnamed: D13.A, D15.A, R42.2
unnamed: R41.1, U21.D1, U21.G2
unnamed: R43.1, U22.D1, U22.G2
unnamed: R44.1, U22.D2
unnamed: D14.A, D16.A, R44.2
unnamed: R46.2, SJ7.3
unnamed: R47.2, SJ7.1
unnamed: C34.1, R49.2, R50.1, U26.3
unnamed: Q9.1, U26.1
unnamed: Q10.3, R51.1
unnamed: Q10.1, R52.2
unnamed: Q9.2, R51.2, U26.4
unnamed: R54.1, U27.D2
unnamed: D17.A, D19.A, R54.2
unnamed: R53.1, U27.D1, U27.G2
unnamed: R55.1, U28.D1, U28.G2
unnamed: R56.1, U28.D2
unnamed: D18.A, D20.A, R56.2
unnamed: R58.2, SJ9.3
unnamed: R59.2, SJ9.1
unnamed: C42.1, R61.2, R62.1, U32.3
unnamed: Q11.1, U32.1
unnamed: Q12.3, R63.1
unnamed: Q12.1, R64.2
unnamed: Q11.2, R63.2, U32.4
unnamed: R66.1, U33.D2
unnamed: D21.A, D23.A, R66.2
unnamed: R65.1, U33.D1, U33.G2
unnamed: R67.1, U34.D1, U34.G2
unnamed: R68.1, U34.D2
unnamed: D22.A, D24.A, R68.2
unnamed: R70.2, SJ11.3
unnamed: R71.2, SJ11.1
unnamed: C50.1, R73.2, R74.1, U38.3
unnamed: Q13.1, U38.1
unnamed: Q14.3, R75.1
unnamed: Q14.1, R76.2
unnamed: Q13.2, R75.2, U38.4
unnamed: R78.1, U39.D2
unnamed: D25.A, D27.A, R78.2
unnamed: R77.1, U39.D1, U39.G2
unnamed: R79.1, U40.D1, U40.G2
unnamed: R80.1, U40.D2
unnamed: D26.A, D28.A, R80.2
unnamed: R82.2, SJ13.3
unnamed: R83.2, SJ13.1
unnamed: C58.1, R85.2, R86.1, U44.3
unnamed: Q15.1, U44.1
unnamed: Q16.3, R87.1
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

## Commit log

2014-02-21 Added blank schematic
    [ZX_Distance_and_Gesture_Sensor.sch]
2014-02-21 Created comm ports, LED drivers, and LED receiver in schematic
    [ZX_Distance_and_Gesture_Sensor.sch]
2014-02-21 Created initial schematic
    [ZX_Distance_and_Gesture_Sensor.brd, ZX_Distance_and_Gesture_Sensor.sch]
2014-02-24 Placed components on PCB and started layout
    [ZX_Distance_and_Gesture_Sensor.brd, ZX_Distance_and_Gesture_Sensor.sch]
2014-02-24 More progress on layout
    [ZX_Distance_and_Gesture_Sensor.brd, ZX_Distance_and_Gesture_Sensor.sch]
2014-02-25 Almost done with layout
    [ZX_Distance_and_Gesture_Sensor.brd]
2014-02-25 Completed layout. Ready for review before prototype.
    [ZX_Distance_and_Gesture_Sensor.brd, ZX_Distance_and_Gesture_Sensor.sch]
2014-02-27 Added trace to DACOUT line. Made test point programming pads smaller. Added extra via on GND plane to beef up current carrying capability.
    [ZX_Distance_and_Gesture_Sensor.brd, ZX_Distance_and_Gesture_Sensor.sch]
2014-02-27 Added width measurement on tdocu layer
    [ZX_Distance_and_Gesture_Sensor.brd]
2014-03-21 Replaced SMD LEDs with PTH. Added PTH Recv'r. Ripped up traces.
    [ZX_Distance_and_Gesture_Sensor.brd, ZX_Distance_and_Gesture_Sensor.sch]
2014-03-25 Grouped components in layout
    [ZX_Distance_and_Gesture_Sensor.brd, ZX_Distance_and_Gesture_Sensor.sch]
2014-03-25 Initial placement of parts for v02.
    [ZX_Distance_and_Gesture_Sensor.brd]
2014-03-25 Initial layout complete for v02.
    [ZX_Distance_and_Gesture_Sensor.brd]
2014-03-26 Reduced board thickness
    [ZX_Distance_and_Gesture_Sensor.brd]
2014-03-27 Added silk pinout. Ready for v02 review.
    [ZX_Distance_and_Gesture_Sensor.brd, ZX_Distance_and_Gesture_Sensor.sch]
2014-03-27 Changed SMT receiver to DNP and removed DNP from PTH receiver and pullup resistor.
    [ZX_Distance_and_Gesture_Sensor.brd, ZX_Distance_and_Gesture_Sensor.sch]
2014-03-28 Swapped TX/RX. Added diagonal trace from GND header to pour.
    [ZX_Distance_and_Gesture_Sensor.brd, ZX_Distance_and_Gesture_Sensor.sch]
2014-03-31 Removed variant names on IR LEDs in schematic
    [ZX_Distance_and_Gesture_Sensor.brd, ZX_Distance_and_Gesture_Sensor.sch]
2014-06-08 Added solder tabs to blinders
    [ZX_Distance_and_Gesture_Sensor.brd, ZX_Distance_and_Gesture_Sensor.sch]
2014-06-08 Added second option for SMT IR LEDs. Added solder pads for blinders.
    [ZX_Distance_and_Gesture_Sensor.brd, ZX_Distance_and_Gesture_Sensor.sch]
2014-07-30 Created initial library and ability to read X and Z data over I2C.
2014-07-30 Completed I2C Gesture Demo. Added skeleton for I2C Gesture Interrupt demo program.
2014-07-31 Added I2C interrupt capabilities and 2 demo programs to show this.
2014-10-09 Updated REFDES numbers. Changed to v04.
    [ZX_Distance_and_Gesture_Sensor_PTH.brd, ZX_Distance_and_Gesture_Sensor_PTH.sch]
2015-01-30 Updated U2, U5, R2. Changed to v05.
    [ZX_Distance_and_Gesture_Sensor_PTH.brd, ZX_Distance_and_Gesture_Sensor_PTH.sch]
2015-02-27 Changed version number. Moved 1 trace. Removed ground pour under part.
    [ZX_Distance_and_Gesture_Sensor_PTH.brd, ZX_Distance_and_Gesture_Sensor_PTH.sch]
2015-03-05 Changed to 1% 10 ohm resistor. Added Arduino I2C address to schematic.
    [ZX_Distance_and_Gesture_Sensor_PTH.brd, ZX_Distance_and_Gesture_Sensor_PTH.sch]
2015-03-05 Added new PDFs of schematic, TOP, and BOT.
2015-03-11 Added name and version to schematic.
    [ZX_Distance_and_Gesture_Sensor_PTH.brd, ZX_Distance_and_Gesture_Sensor_PTH.sch]
2015-03-18 created panel v10
    [ZX_Distance_and_Gesture_Sensor_PTH_Panel_v10.brd]
2015-04-22 added bottom side panel fiducials
    [ZX_Distance_and_Gesture_Sensor_PTH_Panel_v10.brd]
2015-07-06 Squashed 'Libraries/Arduino/' content from commit f176149
    git-subtree-dir: Libraries/Arduino
    git-subtree-split: f176149d0aae691b364d4957dd376a1141b53abc
2015-07-06 Added .gitattributes and renamed Production files.
    [ZX_Distance_and_Gesture_Sensor_PTH_Panel_v10.brd]
2015-07-06 Squashed 'Libraries/Arduino/' content from commit 96e963c
    git-subtree-split: 96e963cafadb52459fd9fc26a9cf7f1abc630121
    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
2015-07-09 Squashed 'Libraries/Arduino/' changes from 96e963c..e6f1c04
    e6f1c04 Fixed typo in library properties file: 'Sensor' to 'Sensors'
    git-subtree-split: e6f1c047240c4442af6a2a33c5a980c5d30a480c
    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
2015-07-09 Squashed 'Libraries/Arduino/' changes from e6f1c04..2e7cfa5
    2e7cfa5 Fixed library name and updated README
    5820c58 Fixed library name
    git-subtree-split: 2e7cfa53d2a9a545d3d10a0513034204c295d3c1
    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
2015-07-09 Fixed Arduino library name
2015-07-30 Updated GestureSense Logo
    [ZX_Distance_and_Gesture_Sensor_PTH.brd, ZX_Distance_and_Gesture_Sensor_PTH.sch]
2015-07-30 v10a panel gerbers (smaller GTO file)
    [ZX_Distance_and_Gesture_Sensor_PTH_Panel_v10a.brd]

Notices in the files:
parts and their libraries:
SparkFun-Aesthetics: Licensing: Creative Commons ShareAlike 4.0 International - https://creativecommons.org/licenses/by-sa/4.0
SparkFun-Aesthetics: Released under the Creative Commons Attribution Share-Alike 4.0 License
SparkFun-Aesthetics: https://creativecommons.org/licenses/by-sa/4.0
